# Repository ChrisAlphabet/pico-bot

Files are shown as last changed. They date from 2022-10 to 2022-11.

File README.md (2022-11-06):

# pico-bot
A two-wheeled self-balancing robot built around the Raspberry Pi Pico

## Useful resources
* https://datasheets.raspberrypi.com/pico/getting-started-with-pico.pdf
* https://datasheets.raspberrypi.com/picow/pico-w-datasheet.pdf
* https://datasheets.raspberrypi.com/rp2040/rp2040-datasheet.pdf 

Start code from a developer prompt so all the env variables are setup properly

## Notes
Mounting holes:
y: 30.6mm
x: 94.6mm 

cargo build --target thumbv7m-none-eabi

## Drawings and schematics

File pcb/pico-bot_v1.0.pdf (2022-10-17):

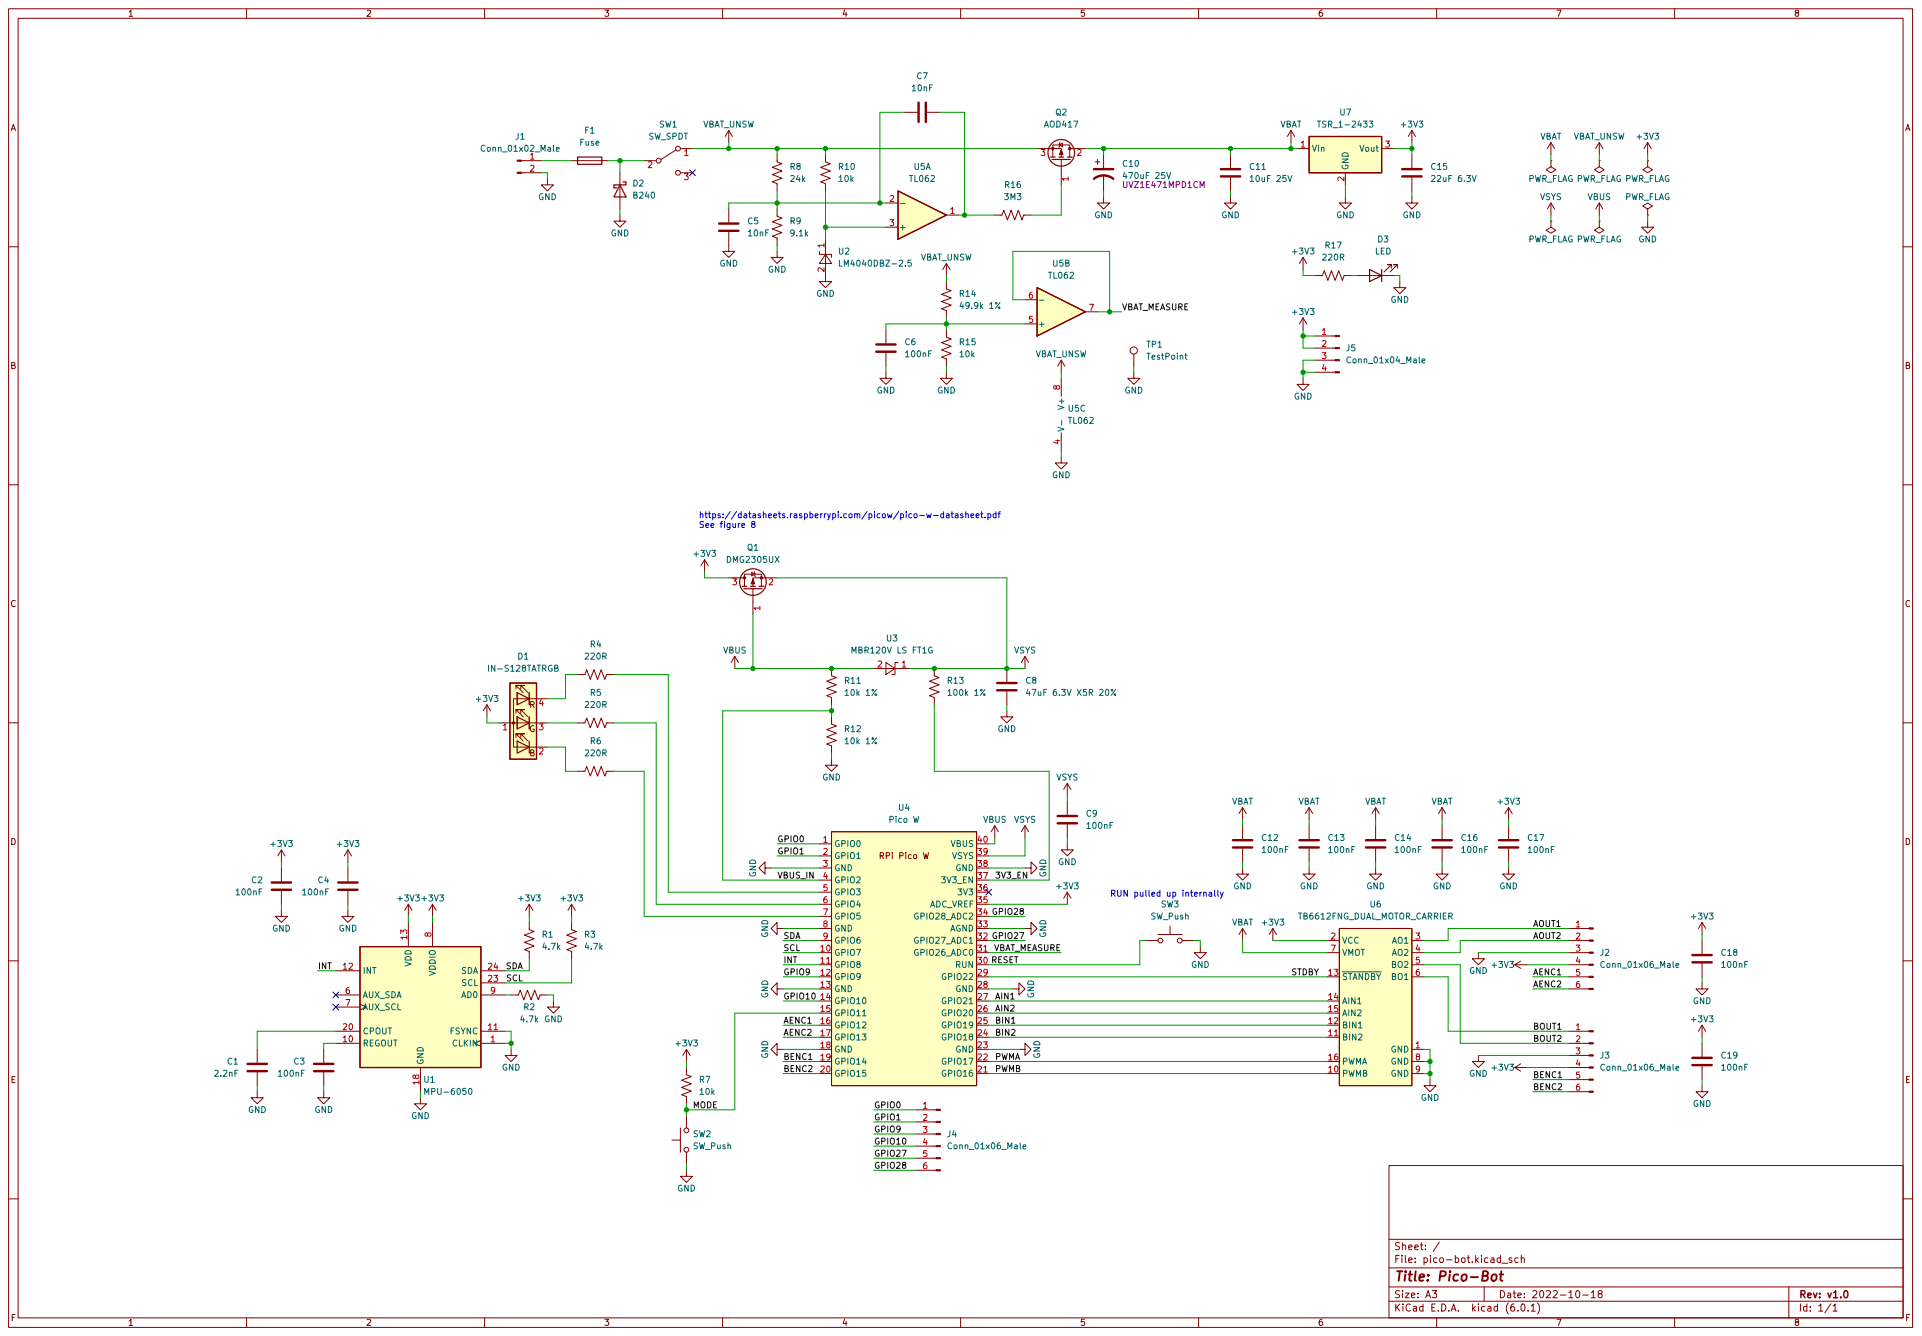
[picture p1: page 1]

https://datasheets.raspberrypi.com/picow/pico-w-datasheet.pdf
See figure 8
10k 1% GND

RUN pulled up internally
SW3 SW_Push

File: pico-bot.kicad_sch Sheet: /
Id: 1/1 Title: Pico-Bot

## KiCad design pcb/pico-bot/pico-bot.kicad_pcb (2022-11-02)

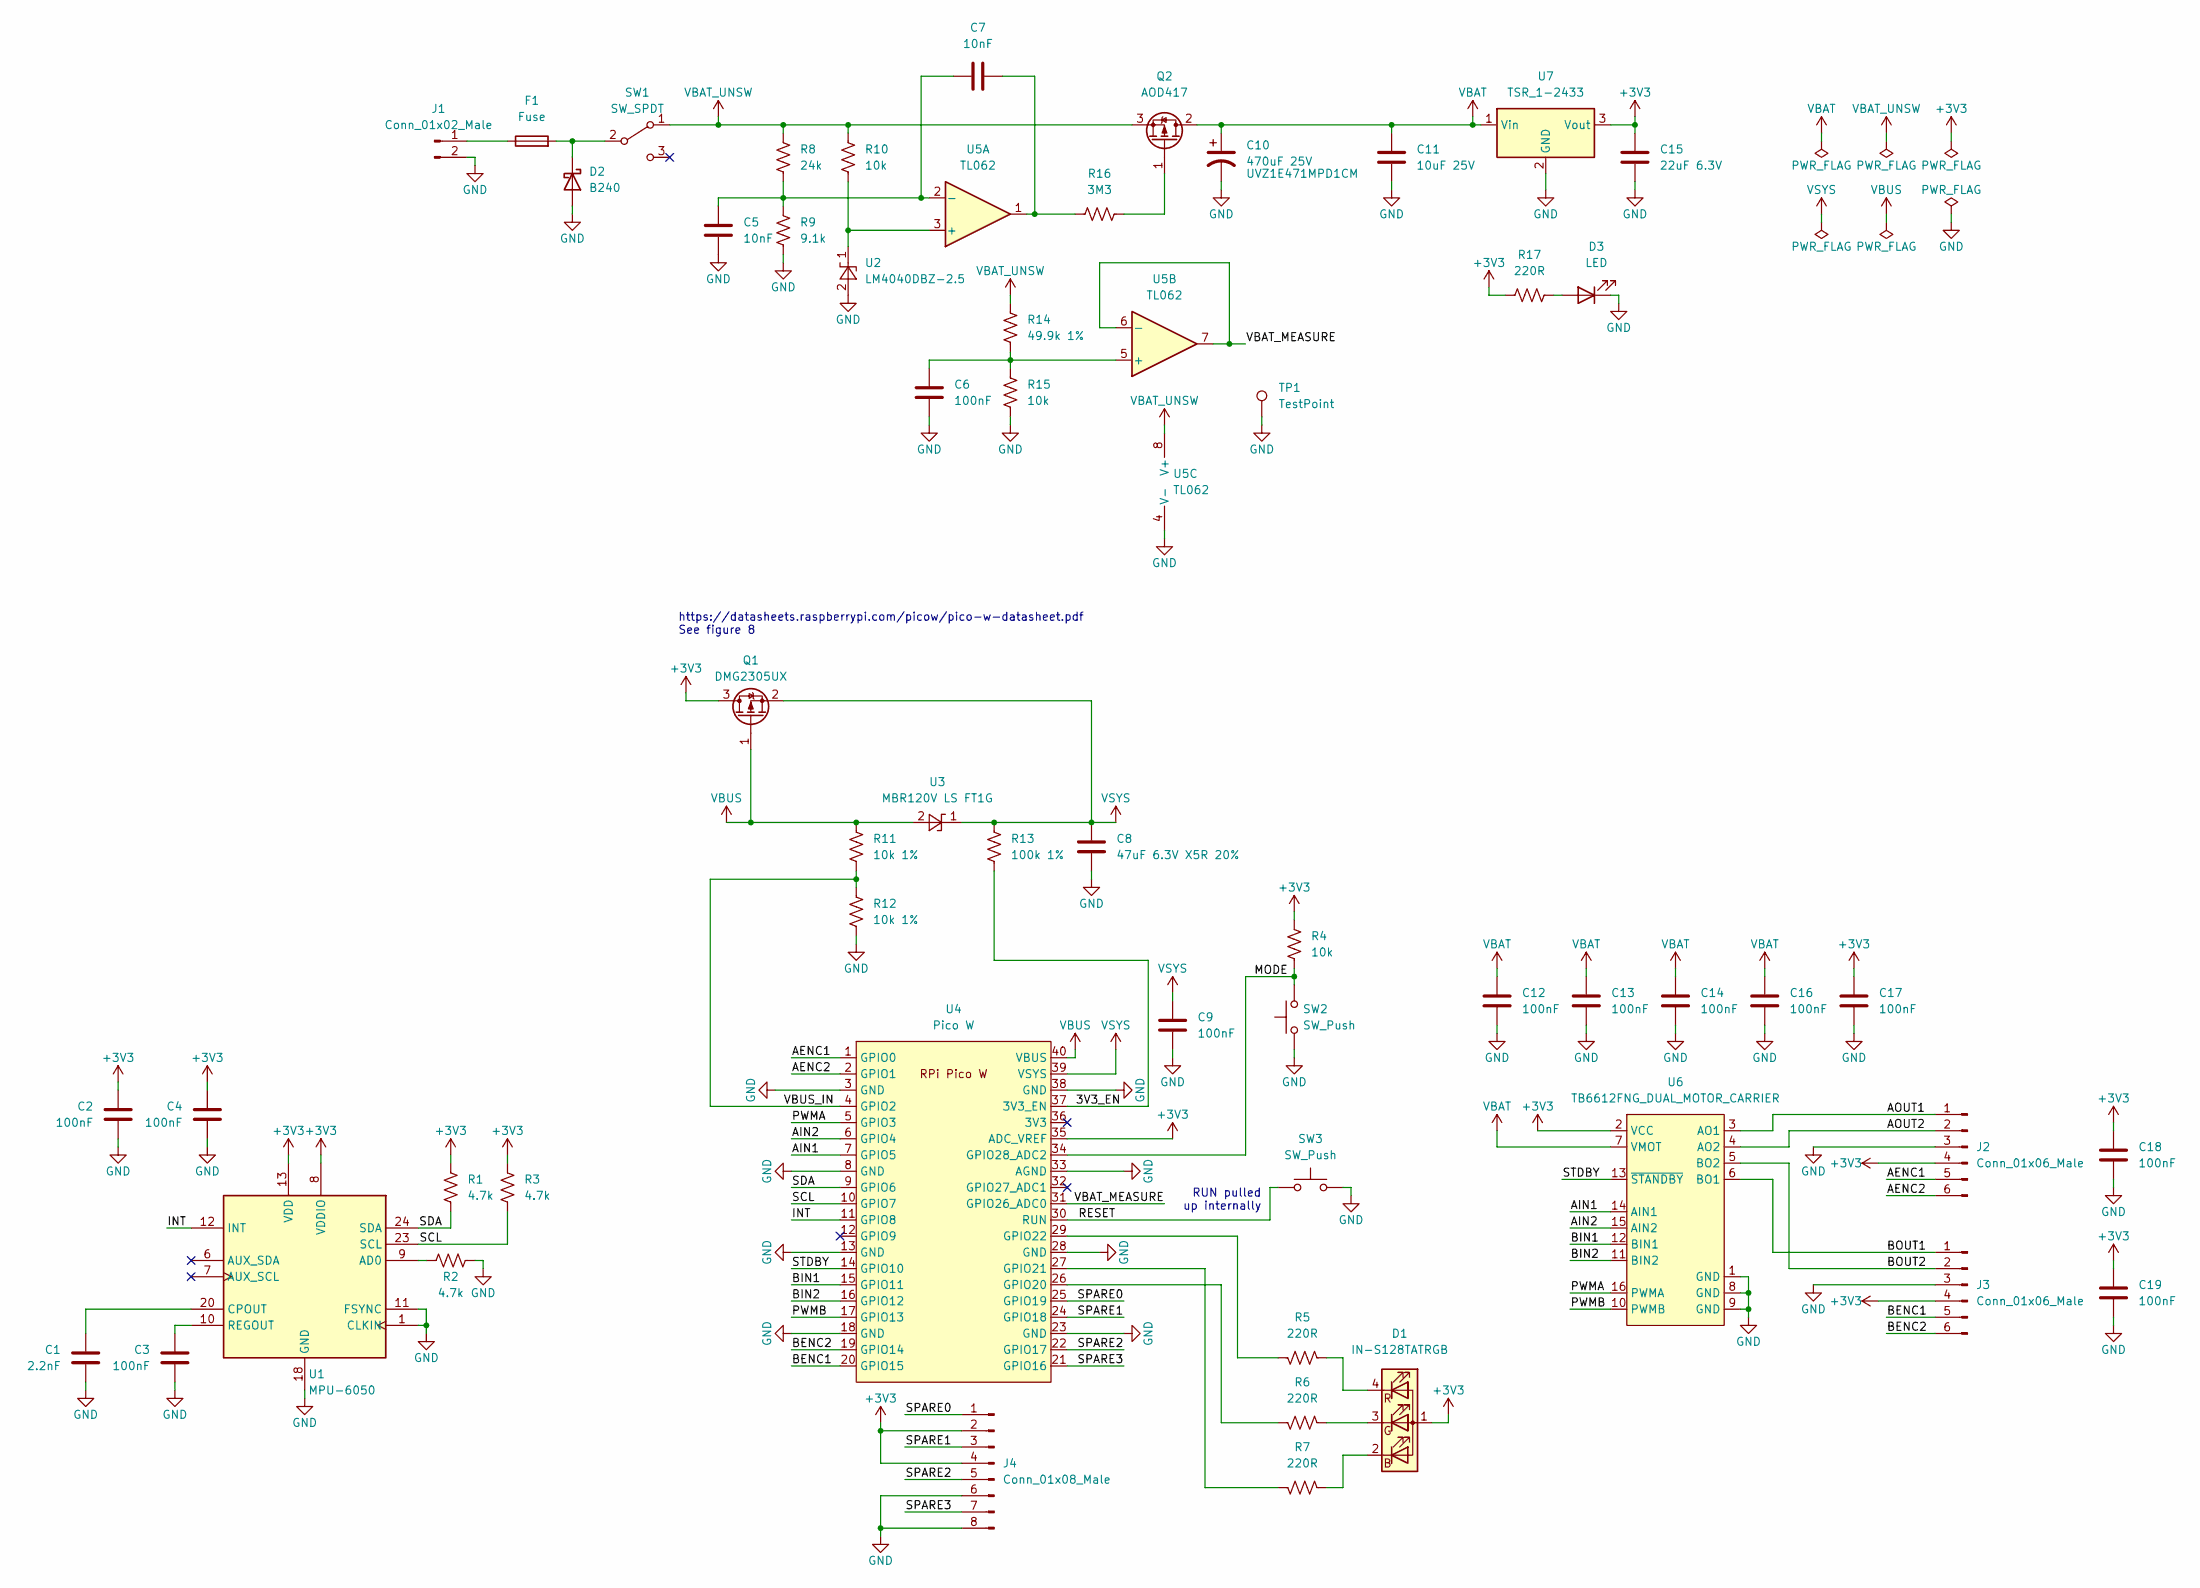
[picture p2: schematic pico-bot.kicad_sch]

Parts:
C1: 2.2nF; C_0805_2012Metric_Pad1.18x1.45mm_HandSolder
C2, C3, C4, C6, C9, C12, C13, C14, C16, C17, C18, C19: 100nF; C_0805_2012Metric_Pad1.18x1.45mm_HandSolder
C5, C7: 10nF; C_0805_2012Metric_Pad1.18x1.45mm_HandSolder
C8: 47uF 6.3V X5R 20%; C_0805_2012Metric_Pad1.18x1.45mm_HandSolder
C10: 470uF 25V; CP_Radial_D10.0mm_P5.00mm; PartNumber UVZ1E471MPD1CM
C11: 10uF 25V; C_1206_3216Metric_Pad1.33x1.80mm_HandSolder
C15: 22uF 6.3V; C_0805_2012Metric_Pad1.18x1.45mm_HandSolder
D1: IN-S128TATRGB; LED_RGB_1210
D2: B240; D_SMB
D3: LED; LED_0805_2012Metric_Pad1.15x1.40mm_HandSolder
F1: Fuse; Fuseholder_Littelfuse_Nano2_154x
J1: Conn_01x02_Male; PinSocket_1x02_P2.54mm_Vertical
J2, J3: Conn_01x06_Male; PinHeader_1x06_P2.54mm_Vertical
J4: Conn_01x08_Male; PinHeader_2x04_P2.54mm_Vertical
Q1: DMG2305UX; SOT-23
Q2: AOD417; TO-252-2
R1, R2, R3: 4.7k; R_0805_2012Metric_Pad1.20x1.40mm_HandSolder
R4, R10, R15: 10k; R_0805_2012Metric_Pad1.20x1.40mm_HandSolder
R5, R6, R7, R17: 220R; R_0805_2012Metric_Pad1.20x1.40mm_HandSolder
R8: 24k; R_0805_2012Metric_Pad1.20x1.40mm_HandSolder
R9: 9.1k; R_0805_2012Metric_Pad1.20x1.40mm_HandSolder
R11, R12: 10k 1%; R_0805_2012Metric_Pad1.20x1.40mm_HandSolder
R13: 100k 1%; R_0805_2012Metric_Pad1.20x1.40mm_HandSolder
R14: 49.9k 1%; R_0805_2012Metric_Pad1.20x1.40mm_HandSolder
R16: 3M3; R_0805_2012Metric_Pad1.20x1.40mm_HandSolder
SW1: SW_SPDT; 1101M2S3CRE2
SW2, SW3: SW_Push; SW_PUSH_6mm
TP1: TestPoint; PinHeader_1x01_P2.54mm_Vertical
U1: MPU-6050; InvenSense_QFN-24_4x4mm_P0.5mm
U2: LM4040DBZ-2.5; SOT-23
U3: MBR120V LS FT1G; D_SOD-123F
U4: Pico W; RPi_Pico_SMD_TH
U5: TL062; SOIC-8-1EP_3.9x4.9mm_P1.27mm_EP2.29x3mm
U6: TB6612FNG_DUAL_MOTOR_CARRIER; TB6612FNG-CARRIER
U7: TSR_1-2433; Converter_DCDC_TRACO_TSR-1_THT

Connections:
+3V3: C2.2, C4.2, C15.2, C17.2, C18.2, C19.2, D1.1 (A), J2.4, J3.4, J4.2, J4.4, Q1.3 (D), R1.2, R3.2, R4.2, R17.1, U1.8 (VDDIO), U1.13 (VDD), U4.35 (ADC_VREF), U6.2 (VCC), U7.3 (Vout)
/3V3_EN: R13.1, U4.37 (3V3_EN)
/AENC1: J2.5, U4.1 (GPIO0)
/AENC2: J2.6, U4.2 (GPIO1)
/AIN1: U4.7 (GPIO5), U6.14 (AIN1)
/AIN2: U4.6 (GPIO4), U6.15 (AIN2)
/AOUT1: J2.1, U6.3 (AO1)
/AOUT2: J2.2, U6.4 (AO2)
/BENC1: J3.5, U4.20 (GPIO15)
/BENC2: J3.6, U4.19 (GPIO14)
/BIN1: U4.15 (GPIO11), U6.12 (BIN1)
/BIN2: U4.16 (GPIO12), U6.11 (BIN2)
/BOUT1: J3.1, U6.6 (BO1)
/BOUT2: J3.2, U6.5 (BO2)
/INT: U1.12 (INT), U4.11 (GPIO8)
/MODE: R4.1, SW2.2, U4.34 (GPIO28_ADC2)
/PWMA: U4.5 (GPIO3), U6.16 (PWMA)
/PWMB: U4.17 (GPIO13), U6.10 (PWMB)
/RESET: SW3.1, U4.30 (RUN)
/SCL: R3.1, U1.23 (SCL), U4.10 (GPIO7)
/SDA: R1.1, U1.24 (SDA), U4.9 (GPIO6)
/SPARE0: J4.1, U4.25 (GPIO19)
/SPARE1: J4.3, U4.24 (GPIO18)
/SPARE2: J4.5, U4.22 (GPIO17)
/SPARE3: J4.7, U4.21 (GPIO16)
/STDBY: U4.14 (GPIO10), U6.13 (~STANDBY)
/VBAT_MEASURE: U4.31 (GPIO26_ADC0), U5.6 (-), U5.7
/VBUS_IN: R11.1, R12.2, U4.4 (GPIO2)
GND: C1.1, C2.1, C3.1, C4.1, C5.1, C6.1, C8.1, C9.1, C10.2, C11.1, C12.1, C13.1, C14.1, C15.1, C16.1, C17.1, C18.1, C19.1, D2.2 (A), D3.1 (K), J1.2, J2.3, J3.3, J4.6, J4.8, R2.1, R9.1, R12.1, R15.1, SW2.1, SW3.2, TP1.1, U1.1 (CLKIN), U1.11 (FSYNC), U1.18 (GND), U2.2 (A), U4.3 (GND), U4.8 (GND), U4.13 (GND), U4.18 (GND), U4.23 (GND), U4.28 (GND), U4.33 (AGND), U4.38 (GND), U5.4 (V-), U6.1 (GND), U6.8 (GND), U6.9 (GND), U7.2 (GND)
unnamed: C1.2, U1.20 (CPOUT)
unnamed: C3.2, U1.10 (REGOUT)
unnamed: C5.2, C7.1, R8.1, R9.2, U5.2 (-)
unnamed: C6.2, R14.1, R15.2, U5.5 (+)
unnamed: C7.2, R16.1, U5.1
unnamed: D1.2 (BK), R7.1
unnamed: D1.3 (GK), R6.1
unnamed: D1.4 (RK), R5.1
unnamed: D2.1 (K), F1.2, SW1.2 (B)
unnamed: D3.2 (A), R17.2
unnamed: F1.1, J1.1
unnamed: Q2.1 (G), R16.2
unnamed: R2.2, U1.9 (AD0)
unnamed: R5.2, U4.29 (GPIO22)
unnamed: R6.2, U4.26 (GPIO20)
unnamed: R7.2, U4.27 (GPIO21)
unnamed: R10.1, U2.1 (K), U5.3 (+)
VBAT: C10.1, C11.2, C12.2, C13.2, C14.2, C16.2, Q2.2 (D), U6.7 (VMOT), U7.1 (Vin)
VBAT_UNSW: Q2.3 (S), R8.2, R10.2, R14.2, SW1.1 (A), U5.8 (V+)
VBUS: Q1.1 (G), R11.2, U3.2 (A), U4.40 (VBUS)
VSYS: C8.2, C9.2, Q1.2 (S), R13.2, U3.1 (K), U4.39 (VSYS)

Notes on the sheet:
RUN pulled up internally
https://datasheets.raspberrypi.com/picow/pico-w-datasheet.pdf See figure 8

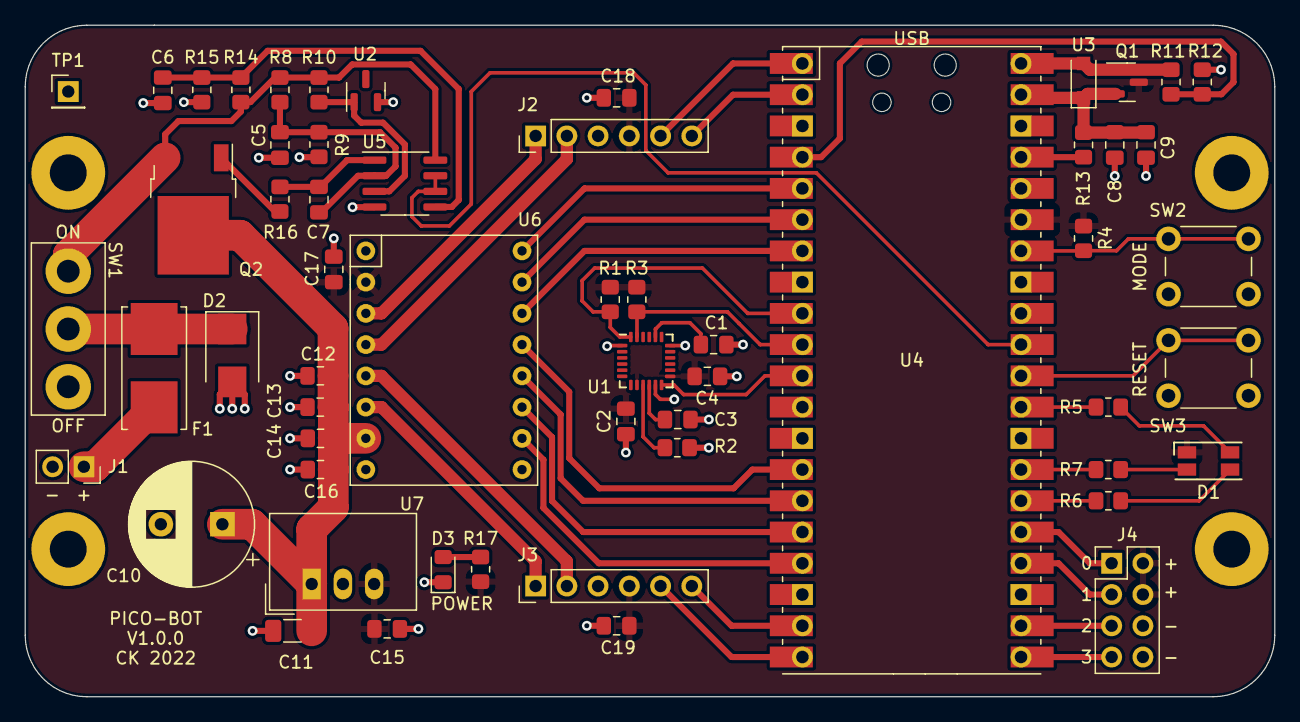
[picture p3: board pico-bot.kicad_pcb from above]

Board: 2 copper layers, 101.6 x 54.6 mm, 57 parts (0 on the bottom side), 50 nets.

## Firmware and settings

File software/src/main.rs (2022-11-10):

//! # Pico Blinky Example
//!
//! Blinks the LED on a Pico board.
//!
//! This will blink an LED attached to GP25, which is the pin the Pico uses for
//! the on-board LED.
//!
//! See the `Cargo.toml` file for Copyright and license details.

#![no_std]
#![no_main]

// The macro for our start-up function
use rp_pico::entry;

// GPIO traits
use embedded_hal::digital::v2::OutputPin;
use embedded_hal::PwmPin;

// Ensure we halt the program on panic (if we don't mention this crate it won't
// be linked)
use panic_halt as _;

// Pull in any important traits
use rp_pico::hal::prelude::*;

// A shorter alias for the Peripheral Access Crate, which provides low-level
// register access
use rp_pico::hal::pac;

// The minimum PWM value (i.e. LED brightness) we want
const LOW: u16 = 0;

// The maximum PWM value (i.e. LED brightness) we want
const HIGH: u16 = 25000;

// A shorter alias for the Hardware Abstraction Layer, which provides
// higher-level drivers.
use rp_pico::hal;

/// Entry point to our bare-metal application.
///
/// The `#[entry]` macro ensures the Cortex-M start-up code calls this function
/// as soon as all global variables are initialised.
///
/// The function configures the RP2040 peripherals, then blinks the LED in an
/// infinite loop.
#[entry]
fn main() -> ! {
    // Grab our singleton objects
    let mut pac = pac::Peripherals::take().unwrap();
    let core = pac::CorePeripherals::take().unwrap();

    // Set up the watchdog driver - needed by the clock setup code
    let mut watchdog = hal::Watchdog::new(pac.WATCHDOG);

    // Configure the clocks
    //
    // The default is to generate a 125 MHz system clock
    let clocks = hal::clocks::init_clocks_and_plls(
        rp_pico::XOSC_CRYSTAL_FREQ,
        pac.XOSC,
        pac.CLOCKS,
        pac.PLL_SYS,
        pac.PLL_USB,
        &mut pac.RESETS,
        &mut watchdog,
    )
    .ok()
    .unwrap();

    // The delay object lets us wait for specified amounts of time (in
    // milliseconds)
    let mut delay = cortex_m::delay::Delay::new(core.SYST, clocks.system_clock.freq().to_Hz());

    // The single-cycle I/O block controls our GPIO pins
    let sio = hal::Sio::new(pac.SIO);

    // Init PWMs
    let mut pwm_slices = hal::pwm::Slices::new(pac.PWM, &mut pac.RESETS);

    // Configure PWM4
    let pwm = &mut pwm_slices.pwm4;
    pwm.set_ph_correct();
    pwm.enable();

    // Set the pins up according to their function on this particular board
    let pins = rp_pico::Pins::new(
        pac.IO_BANK0,
        pac.PADS_BANK0,
        sio.gpio_bank0,
        &mut pac.RESETS,
    );

    // Set the LED to be an output
    // let mut led_pin = pins.led.into_push_pull_output();

    // // Blink the LED at 1 Hz
    // loop {
    //     led_pin.set_high().unwrap();
    //     delay.delay_ms(500);
    //     led_pin.set_low().unwrap();
    //     delay.delay_ms(500);
    // }

    // Output channel B on PWM4 to the LED pin
    let channel = &mut pwm.channel_b;
    channel.output_to(pins.led);

    // Infinite loop, fading LED up and down
    loop {
        // Ramp brightness up
        for i in (LOW..=HIGH).skip(100) {
            delay.delay_us(8);
            channel.set_duty(i);
        }

        // Ramp brightness down
        for i in (LOW..=HIGH).rev().skip(100) {
            delay.delay_us(8);
            channel.set_duty(i);
        }

        delay.delay_ms(500);
    }
}

// End of file

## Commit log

2022-10-13 Create kicad project, add motor driver, ignore kicad backups
    [pico-bot.kicad_pcb, pico-bot.kicad_sch]
2022-10-15 Add tb6612fng and mpu6050
    [pico-bot.kicad_sch]
2022-10-15 Add power circuit up to regulator
    [pico-bot.kicad_sch]
2022-10-15 Finish power circuit
    [pico-bot.kicad_sch]
2022-10-15 Add motor controller and imu circuits, create rpi pico w
    [pico-bot.kicad_sch]
2022-10-15 Progress commit
    [pico-bot.kicad_sch]
2022-10-16 Add pico external power circuit, wire up pico
    [pico-bot.kicad_sch]
2022-10-16 Add sw, rgb, update footprints
    [pico-bot.kicad_sch]
2022-10-16 Use mpu6050 directly instead of carrier board
    [pico-bot.kicad_sch]
2022-10-16 Add annotations to schematic
    [pico-bot.kicad_sch]
2022-10-16 Add pico-sdk as a submodule, add useful links to readme
2022-10-16 Add a wip schematic pdf
2022-10-17 Add ERC fixes, route unused GPIO and pwr/gnd to pins
    [pico-bot.kicad_sch]
2022-10-17 Update schematic pdf
    [pico-bot.kicad_sch]
2022-10-20 Fix missing footprints, add parts to PCB
    [pico-bot.kicad_pcb, pico-bot.kicad_sch]
2022-10-22 Define mounting hole locations
    [pico-bot.kicad_pcb]
2022-10-25 Group circuits together on PCB
    [pico-bot.kicad_pcb]
2022-10-25 Group undervoltage protection circuit components
    [pico-bot.kicad_pcb]
2022-10-29 Add rough board outline
    [pico-bot.kicad_pcb]
2022-10-29 Finish init placement of components
    [pico-bot.kicad_pcb]
2022-10-29 Route power and input protection
    [pico-bot.kicad_pcb]
2022-10-30 Partial route mpu6050
    [pico-bot.kicad_pcb]
2022-10-30 Rework pin allocation to ease layout
    [pico-bot.kicad_pcb, pico-bot.kicad_sch]
2022-10-31 Center and route MPU-6050
    [pico-bot.kicad_pcb]
2022-10-31 Route pico power select circuit
    [pico-bot.kicad_pcb]
2022-10-31 Route all except power and ground
    [pico-bot.kicad_pcb, pico-bot.kicad_sch]
2022-11-01 Add pours, pour currently broken
    [pico-bot.kicad_pcb]
2022-11-02 Update pour clearance and repour, now all nets are connected
    [pico-bot.kicad_pcb]
2022-11-02 Address DRC warnings
    [pico-bot.kicad_pcb]
2022-11-02 Update silkscreen
    [pico-bot.kicad_pcb]
2022-11-06 Add pico project template
2022-11-10 Add pwm from rp-hal example
